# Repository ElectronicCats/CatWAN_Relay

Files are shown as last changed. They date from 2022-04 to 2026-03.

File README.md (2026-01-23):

# CatWAN Soldering Station - Control de Cautines con NFC

## Descripción

Sistema de control de cautines mediante autenticación NFC MIFARE S50 para ESP32-C6. Permite controlar el encendido y apagado de cautines solo con tarjetas NFC autorizadas, registrando todos los eventos en Google Sheets o n8n. Soporta múltiples dispositivos con identificadores únicos.

Incluye **feedback visual avanzado mediante pantalla OLED**, mostrando estados del sistema, conexión WiFi, eventos NFC y errores.

## Características

Este proyecto está diseñado como un sistema industrial ligero, robusto y escalable para el control de cautines mediante autenticación NFC. A continuación se describen las características de forma más detallada:

* ✅ **Autenticación NFC MIFARE S50**
  El sistema valida tarjetas NFC autorizadas usando su UID. Las tarjetas no autorizadas son rechazadas y el evento queda registrado.

* ✅ **Control de múltiples cautines (hasta 3 relés por dispositivo)**
  Cada tarjeta puede estar asociada a un relé específico o usar un relé por defecto. Esto permite que un solo dispositivo controle varias estaciones.

* ✅ **Gestión persistente de tarjetas autorizadas (SPIFFS)**
  Las tarjetas y asignaciones se almacenan en memoria flash, por lo que no se pierden al reiniciar el equipo.

* ✅ **Asignación manual de tarjetas a relés**
  Mediante comandos seriales es posible asignar una tarjeta a un cautín específico.

* ✅ **Identificador único de dispositivo (Device ID)**
  Cada ESP32 tiene un identificador único configurable que permite distinguir eventos cuando se usan múltiples estaciones.

* ✅ **Registro de eventos en Google Sheets o n8n**
  Todos los eventos (éxito, fallo, encendido, apagado, timeout) se envían vía HTTP en formato JSON.

* ✅ **WiFiManager con Captive Portal**
  Permite configurar WiFi y la URL de n8n sin recompilar el firmware.

* ✅ **Feedback visual mediante OLED y LED**
  La pantalla OLED muestra el estado del sistema (bienvenida, esperando tarjeta, tarjeta válida, errores, timeout).

* ✅ **Sistema de seguridad con timeout automático**
  Si un cautín permanece encendido más del tiempo configurado, se apaga automáticamente.

* ✅ **Comandos seriales para gestión y debug**
  Permite mantenimiento y diagnóstico sin necesidad de reprogramar el equipo.

* ✅ Autenticación NFC MIFARE S50

* ✅ Control de múltiples cautines (hasta 3 relés por dispositivo)

* ✅ Gestión de tarjetas autorizadas (almacenamiento local SPIFFS)

* ✅ Asignación manual de tarjetas a relés específicos

* ✅ Identificador único de dispositivo (Device ID)

* ✅ Registro de eventos en Google Sheets o n8n

* ✅ WiFi Manager con captive portal para configuración

* ✅ Feedback visual por **pantalla OLED (I2C)**

* ✅ Feedback visual por LED verde

* ✅ Sistema de seguridad con timeout automático (2 horas)

* ✅ Comandos seriales para gestión y debug

## Hardware Requerido

* **ESP32-C6** - Microcontrolador con WiFi
* **PN532** - Módulo NFC (I2C)
* **Pantalla OLED** - SSD1306 / SH1106 (I2C)
* **Relé/es** - Para controlar cautín/es (hasta 3 por dispositivo)
* **LED Verde** - Feedback de éxito
* **Fuente de alimentación** - 5V o 3.3V según requerimientos

## Conexiones Hardware

### PN532 (I2C)

* VCC → 3.3V
* GND → GND
* SDA → I2C Data (pines por defecto del ESP32-C6)
* SCL → I2C Clock (pines por defecto del ESP32-C6)

### Pantalla OLED (I2C)

* VCC → 3.3V
* GND → GND
* SDA → I2C Data
* SCL → I2C Clock

**Nota:** El PN532 y la OLED comparten el bus I2C.

### Relés

* RELAY_1 → GPIO 8 (Cautín 1)
* RELAY_2 → GPIO 10 (Cautín 2)
* RELAY_3 → GPIO 1 (Cautín 3)

### Feedback

* LED_GREEN → GPIO 11

**Nota:** Los pines son configurables en `config.h`

## Instalación

### 1. Librerías Requeridas

Instala las siguientes librerías desde el Arduino Library Manager:

* **Adafruit PN532** – Comunicación NFC
* **WiFiManager** – Gestión de WiFi
* **ArduinoJson** – Parsing de JSON
* **Adafruit SSD1306** – Control de pantalla OLED
* **Adafruit GFX Library** – Gráficos para OLED
* **SPIFFS** – Sistema de archivos (incluido en ESP32)

### 2. Archivos Nuevos Añadidos

El proyecto incluye un gestor dedicado para la pantalla OLED:

```
/oledManager.h
/oledManager.cpp
```

**Funciones principales de `oledManager`:**

* Inicialización de la pantalla
* Mensajes de estado (boot, WiFi, NFC)
* Visualización de UID
* Mensajes de éxito / error
* Indicadores de envío HTTP

### 3. Configuración

1. Abre `config.h` y configura:

   * `DEVICE_ID`
   * Pines de relés y LED
   * URL de Google Sheets o n8n
   * Parámetros de seguridad

2. Configura el tipo de backend:

```cpp
#define USE_GOOGLE_APPS_SCRIPT false
#define USE_N8N true
```

3. Configura la URL del webhook de n8n:

```cpp
#define N8N_WEBHOOK_URL "https://tu-n8n/webhook/catwan"
```

## Documentación de Funciones Principales

### setup()

Función de inicialización del sistema. Se ejecuta una sola vez al encender el dispositivo.

Responsabilidades:

* Inicializar comunicación serial
* Montar SPIFFS
* Configurar WiFi mediante WiFiManager
* Inicializar PN532
* Inicializar pantalla OLED
* Mostrar mensaje de bienvenida

---

### loop()

Función principal de ejecución continua.

Responsabilidades:

* Verificar conexión WiFi
* Revisar si el sistema está listo
* Mostrar estado "Esperando tarjeta" en OLED
* Detectar tarjetas NFC
* Procesar lógica de autorización
* Controlar relés
* Enviar eventos HTTP
* Manejar timeouts

---

### NFCManager::begin()

Inicializa el módulo PN532 y verifica que esté correctamente conectado por I2C.

### NFCManager::isCardPresent()

Devuelve `true` si una tarjeta NFC está presente en el lector.

### NFCManager::readCardUID()

Lee el UID de la tarjeta detectada y lo devuelve como `String`.

### NFCManager::reset()

Reinicia el estado del lector para evitar múltiples lecturas de la misma tarjeta.

---

### OLEDManager::showWelcome()

Muestra un mensaje de bienvenida al encender el dispositivo.

### OLEDManager::showWaiting()

Muestra el mensaje "Esperando tarjeta NFC" cuando el sistema está en reposo.

### OLEDManager::showCardAdded(uid)

Muestra el UID de la tarjeta detectada y confirma la acción realizada.

### OLEDManager::showTimeout()

Muestra un mensaje de error cuando se excede el tiempo de espera para detectar tarjeta.

---

### sendEventToN8n(json)

Envía un payload JSON vía HTTP POST a n8n o Google Sheets.
Incluye información del dispositivo, tarjeta, acción y duración.

---

## Uso

### Primera Configuración WiFi

1. El dispositivo crea un AP:

   * **SSID:** `CatWAN-SolderingStation`
   * **Password:** `soldering123`
2. Configura tu red WiFi desde el portal cautivo
3. El estado se muestra en la pantalla OLED

### Operación Normal

1. Presenta tarjeta NFC
2. OLED muestra UID y acción
3. Relé cambia de estado
4. Evento enviado a Google Sheets o n8n
5. OLED confirma envío exitoso

## Arquitectura del Software

El firmware está organizado de forma modular para facilitar mantenimiento, escalabilidad y depuración. Cada módulo tiene una responsabilidad clara.

### Módulos Principales

* **CATWAN_RELAY.ino**
  Archivo principal. Contiene `setup()` y `loop()`, coordina todos los managers y define el flujo general del sistema.

* **NFCManager**
  Encapsula toda la lógica relacionada con el PN532:

  * Inicialización del lector NFC
  * Detección de tarjetas
  * Lectura del UID
  * Reset del lector para evitar lecturas duplicadas

* **CardManager**
  Gestiona las tarjetas autorizadas:

  * Agregar / eliminar tarjetas
  * Asignar tarjetas a relés
  * Guardar y leer datos desde SPIFFS

* **RelayManager**
  Controla los relés físicos:

  * Encender / apagar relés
  * Llevar control del estado actual
  * Medir tiempo de encendido

* **WiFiManagerHelper**
  Extiende WiFiManager para:

  * Configurar WiFi
  * Configurar la URL de n8n desde el captive portal

* **OLEDManager (nuevo)**
  Maneja la pantalla OLED por I2C:

  * Mensaje de bienvenida
  * Estado "Esperando tarjeta"
  * Mostrar UID leído
  * Mostrar mensajes de error y timeout

* **FeedbackManager**
  Controla el LED verde para indicar éxito visual inmediato.

---

## Flujo General del Sistema

```text
[ Encendido ]
      |
      v
[ Inicialización ]
- Serial
- WiFi
- SPIFFS
- PN532
- OLED
      |
      v
[ Mostrar Bienvenida OLED ]
      |
      v
[ Esperando Tarjeta NFC ] <-------------------+
      |                                      |
      v                                      |
[ Tarjeta Detectada ]                         |
      |                                      |
      v                                      |
[ ¿Tarjeta Autorizada? ] -- NO --> [ Error ] -+
      |
     SI
      |
      v
[ Activar / Desactivar Relé ]
      |
      v
[ Enviar JSON a n8n / Sheets ]
      |
      v
[ Mostrar Resultado en OLED ]
      |
      v
[ Volver a Espera ]
```

---

## Estructura de Datos

### JSON enviado por ESP32

### JSON enviado a n8n

```json
{
  "ts": "02:30:45",
  "dev": "ESTACION1",
  "uid": "04A5B6C7D8",
  "act": "ENCENDER",
  "st": "EXITO",
  "rel": 0,
  "dur": 120000
}
```

### Uso del JSON en n8n

En n8n el JSON puede usarse para:

* Buscar usuario por UID
* Buscar estación por Device ID
* Registrar eventos
* Calcular tiempo de uso
* Activar alertas o dashboards

## Flujo del Sistema

1. Lectura NFC
2. Validación local
3. Acción sobre relé
4. Feedback OLED + LED
5. Envío HTTP POST
6. Registro centralizado

## Seguridad

* Timeout automático configurable
* Debounce de lecturas NFC
* Registro de intentos fallidos
* Sin almacenamiento de nombres en el ESP32

## Troubleshooting

### HTTP Error: -1

* No hay conexión WiFi
* URL inválida
* Error DNS
* Webhook n8n inactivo

### OLED no muestra información

* Verifica dirección I2C (0x3C / 0x3D)
* Verifica librerías Adafruit
* Confirma alimentación estable

---
## Licencia

Este firmware está bajo licencia GNU AGPL v3.0.

---

## 👨‍💻 Autor

ElectronicCats.

---
## Soporte

Para más información, visita: https://electroniccats.com

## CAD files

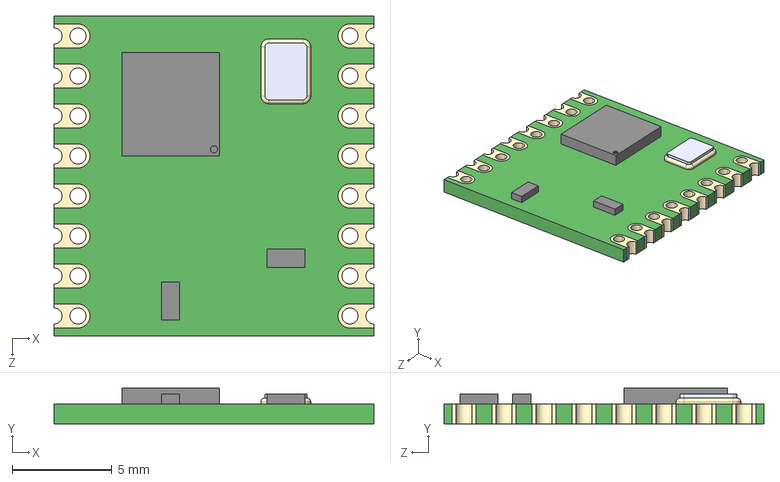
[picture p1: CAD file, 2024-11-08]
Hw/3D/RFM95W-915S2--3DModel-STEP-56544.STEP
16.0 x 1.80 x 16.0 mm

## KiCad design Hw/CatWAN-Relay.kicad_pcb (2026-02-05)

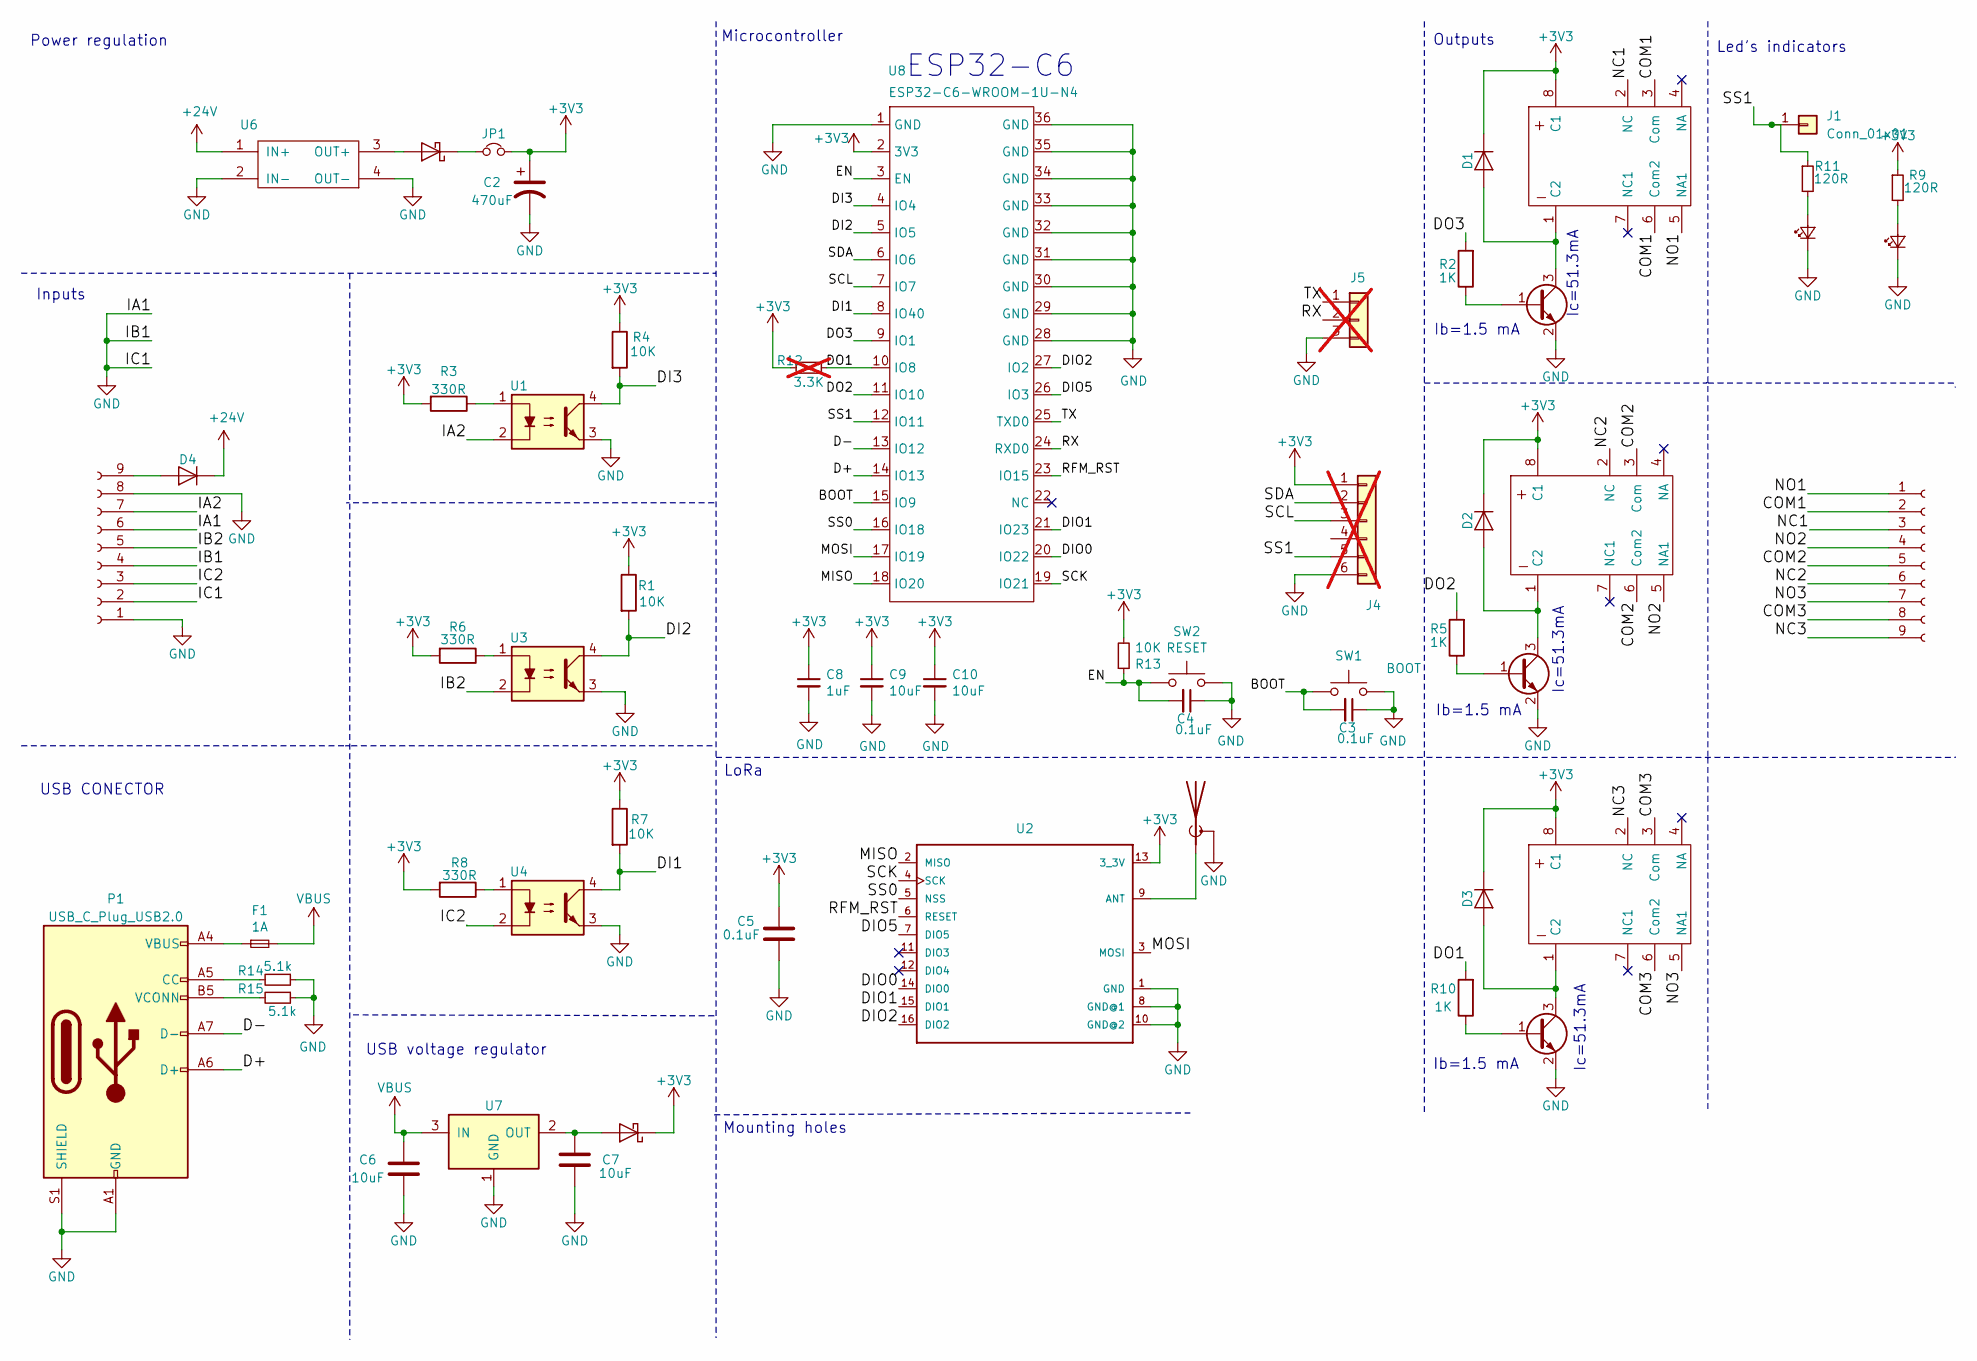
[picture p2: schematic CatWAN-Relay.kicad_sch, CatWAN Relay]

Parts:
AE1: Antenna_Shield; U.FL_Molex_MCRF_73412-0110_Vertical; LCSC# C7426714
C2: 470uF; C_Elec_6.3x7.7; LCSC# C5354997
C3, C4, C5: 0.1uF; C_0603_1608Metric; LCSC# C15725
C6, C7, C9, C10: 10uF; C_0603_1608Metric; LCSC# C85713
C8: 1uF; C_0603_1608Metric; LCSC# C15849
D1, D2, D3, D4: SOD4007-MS; D_SOD-123F; LCSC# C3008061
D5, D8: MBR120; D_SOD-123; LCSC# C130880
D6: ON; LED_0805_2012Metric_Pad1.15x1.40mm_HandSolder; LCSC# C130114
D7: SS0_LED; LED_0805_2012Metric_Pad1.15x1.40mm_HandSolder; LCSC# C130114
F1: 1A; Fuse_0603_1608Metric; LCSC# C151139
J1: Conn_01x01; PinHeader_1x01_P2.54mm_Vertical
J2: INPUTS; TerminalBlock_Phoenix_MKDS-1,5-9-5.08_1x09_P5.08mm_Horizont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
J3: OUTPUTS; TerminalBlock_Phoenix_MKDS-1,5-9-5.08_1x09_P5.08mm_Horizont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
J4: I2C; PinHeader_1x06_P2.54mm_Vertical; not fitted
J5: Serial; PinHeader_1x03_P2.54mm_Vertical; not fitted
JP1: ADJ; PinHeader_1x02_P2.54mm_Vertical
P1: USB_C_Plug_USB2.0; C393939; LCSC# C393939
Q1, Q2, Q3: MMBT2222A; SOT-23; LCSC# C916372
R1, R4, R7, R13: 10K; R_0603_1608Metric; LCSC# C15401
R2, R5, R10: 1K; R_0603_1608Metric; LCSC# C115325
R3, R6, R8: 330R; R_0603_1608Metric; LCSC# C25231
R9, R11: 120R; R_0603_1608Metric; LCSC# C22787
R12: 3.3K; R_0603_1608Metric; not fitted
R14, R15: 5.1k; R_0603_1608Metric; LCSC# C122969
SW1: BOOT; SW_Push_SPST_NO_Alps_SKRK; LCSC# C455281
SW2: RESET; SW_Push_SPST_NO_Alps_SKRK; LCSC# C455281
U1, U3, U4: AT3H7C-CuH-S; SOP-4_4.4x2.6mm_P1.27mm; LCSC# C20612661
U2: RFM95W-915-868; RFM95W
U6: LM2596_DC-DC; LM2596DC-DC
U7: AP2114H-3.3TRG1; SOT-223-3_TabPin2; LCSC# C150716
U8: ESP32-C6-WROOM-1U-N4; ESP32-C6-WROOM-1U
Y1, Y2, Y3: UD2-3NU; LCSC# C90259

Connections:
+3V3: C2.1, C5.1, C8.1, C9.1, C10.1, D1.1 (K), D2.1 (K), D3.1 (K), D5.1 (K), J4.1, JP1.2, R1.1, R3.2, R4.1, R6.2, R7.1, R8.2, R9.1, R12.2, R13.2, U2.13 (3_3V), U8.2 (3V3), Y1.8 (C1), Y2.8 (C1), Y3.8 (C1)
+24V: D4.1 (K), U6.1 (IN+)
/<NO NET>: J4.4
/BOOT: C3.2, SW1.2, U8.15 (IO9)
/COM1: J3.2, Y1.3 (Com), Y1.6 (Com2)
/COM2: J3.5, Y2.3 (Com), Y2.6 (Com2)
/COM3: J3.8, Y3.3 (Com), Y3.6 (Com2)
/D+: P1.A6 (D+), U8.14 (IO13)
/D-: P1.A7 (D-), U8.13 (IO12)
/DI1: R7.2, U4.4, U8.8 (IO40)
/DI2: R1.2, U3.4, U8.5 (IO5)
/DI3: R4.2, U1.4, U8.4 (IO4)
/DIO0: U2.14 (DIO0), U8.20 (IO22)
/DIO1: U2.15 (DIO1), U8.21 (IO23)
/DIO2: U2.16 (DIO2), U8.27 (IO2)
/DIO5: U2.7 (DIO5), U8.26 (IO3)
/DO1: R10.2, R12.1, U8.10 (IO8)
/DO2: R5.2, U8.11 (IO10)
/DO3: R2.2, U8.9 (IO1)
/EN: C4.2, R13.1, SW2.2, U8.3 (EN)
/IA2: J2.7, U1.2
/IB2: J2.5, U3.2
/IC2: J2.3, U4.2
/MISO: U2.2 (MISO), U8.18 (IO20)
/MOSI: U2.3 (MOSI), U8.17 (IO19)
/NC1: J3.3, Y1.2 (NC)
/NC2: J3.6, Y2.2 (NC)
/NC3: J3.9, Y3.2 (NC)
/NO1: J3.1, Y1.5 (NA1)
/NO2: J3.4, Y2.5 (NA1)
/NO3: J3.7, Y3.5 (NA1)
/RFM_RST: U2.6 (RESET), U8.23 (IO15)
/RX: J5.2, U8.24 (RXD0)
/SCK: U2.4 (SCK), U8.19 (IO21)
/SCL: J4.3, U8.7 (IO7)
/SDA: J4.2, U8.6 (IO6)
/SS0: U2.5 (NSS), U8.16 (IO18)
/SS1: J1.1, J4.5, R11.1, U8.12 (IO11)
/TX: J5.1, U8.25 (TXD0)
GND: AE1.2 (Shield), C2.2, C3.1, C4.1, C5.2, C6.2, C7.2, C8.2, C9.2, C10.2, D6.1 (K), D7.1 (K), J2.1, J2.2, J2.4, J2.6, J2.8, J4.6, J5.3, P1.A1 (GND), P1.A12 (GND), P1.B1 (GND), P1.B12 (GND), P1.S1 (SHIELD), Q1.2 (E), Q2.2 (E), Q3.2 (E), R14.1, R15.1, SW1.1, SW2.1, U1.3, U2.1 (GND), U2.8 (GND@1), U2.10 (GND@2), U3.3, U4.3, U6.2 (IN-), U6.4 (OUT-), U7.1 (GND), U8.1 (GND), U8.28 (GND), U8.29 (GND), U8.30 (GND), U8.31 (GND), U8.32 (GND), U8.33 (GND), U8.34 (GND), U8.35 (GND), U8.36 (GND), U8.37 (GND)
unnamed: AE1.1 (A), U2.9 (ANT)
unnamed: D1.2 (A), Q1.3 (C), Y1.1 (C2)
unnamed: D2.2 (A), Q2.3 (C), Y2.1 (C2)
unnamed: D3.2 (A), Q3.3 (C), Y3.1 (C2)
unnamed: D4.2 (A), J2.9
unnamed: C7.1, D5.2 (A), U7.2 (OUT)
unnamed: D6.2 (A), R9.2
unnamed: D7.2 (A), R11.2
unnamed: D8.2 (A), U6.3 (OUT+)
unnamed: D8.1 (K), JP1.1
unnamed: F1.1, P1.A4 (VBUS), P1.A9 (VBUS), P1.B4 (VBUS), P1.B9 (VBUS)
unnamed: P1.A5 (CC), R14.2
unnamed: P1.B5 (VCONN), R15.2
unnamed: Q1.1 (B), R2.1
unnamed: Q2.1 (B), R5.1
unnamed: Q3.1 (B), R10.1
unnamed: R3.1, U1.1
unnamed: R6.1, U3.1
unnamed: R8.1, U4.1
VBUS: C6.1, F1.2, U7.3 (IN)

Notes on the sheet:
LoRa
Inputs
Microcontroller
Ic=51.3mA
USB voltage regulator
USB CONECTOR
Power regulation
Mounting holes
ESP32-C6
Ib=1.5 mA
Led's indicators
Outputs

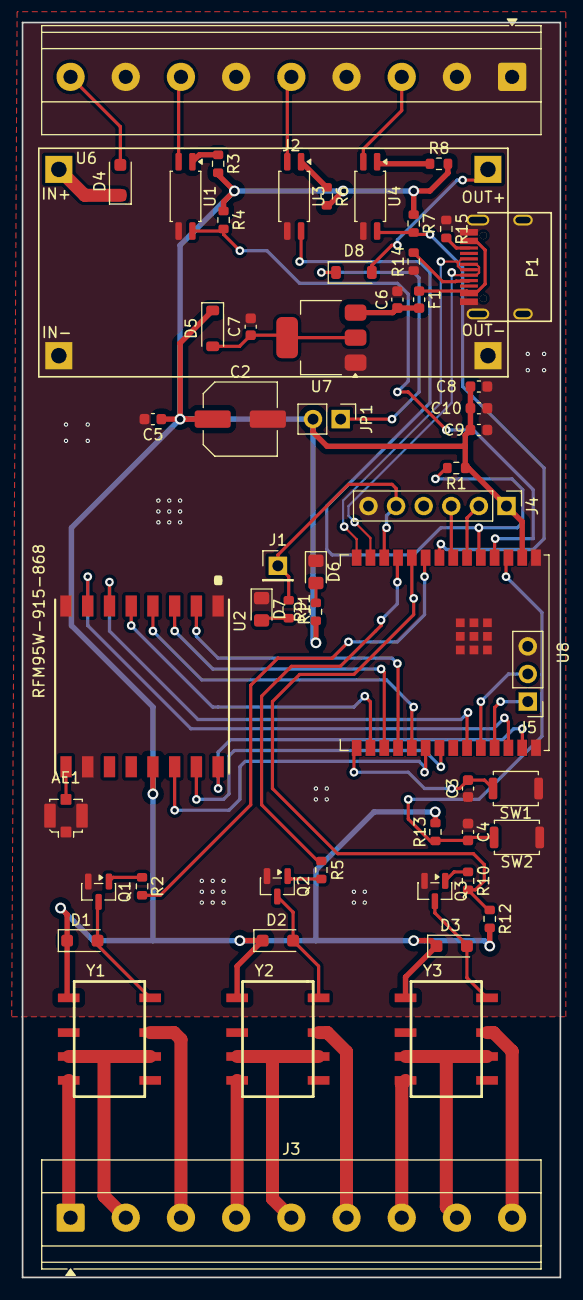
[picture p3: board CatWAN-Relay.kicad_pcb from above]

Board: 2 copper layers, 49.5 x 115.5 mm, 56 parts (0 on the bottom side), 59 nets.

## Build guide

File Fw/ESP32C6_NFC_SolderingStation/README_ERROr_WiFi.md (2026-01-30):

# 📘 README – Corrección de errores NFC y sobresaturación por WiFiManager

## 1. Contexto del problema

Durante el desarrollo del proyecto **CATWAN_RELAY**, se integraron varios módulos críticos en un ESP32, principalmente:

* **PN532 (NFC) vía I2C**
* **WiFiManager** para configuración dinámica de red
* Comunicación con servicios externos (n8n)

Conforme el proyecto creció, comenzaron a presentarse errores constantes relacionados con NFC, identificados principalmente como **"NFC ERROR"**, pérdida total de detección de tarjetas y ausencia de mensajes por el monitor Serial.

---

## 2. Síntomas observados

1. El monitor Serial dejaba de mostrar información después de cargar nuevo código.
2. El PN532 no detectaba tarjetas NFC aunque el cableado fuera correcto.
3. Aparecían errores de compilación y linker relacionados con `NFCManager`.
4. WiFiManager se quedaba bloqueado o reiniciaba el sistema.
5. El sistema funcionaba parcialmente si se deshabilitaba WiFiManager o NFC, pero no ambos juntos.

---

## 3. Causas reales del problema

### 3.1 Sobresaturación del sistema por WiFiManager

WiFiManager crea:

* Portales cautivos
* Servidor web
* DNS interno

Esto **consume memoria, tiempo de CPU y bloquea el loop principal**, especialmente si:

* Se inicializa antes que otros periféricos
* No se limita su tiempo de ejecución

Esto provocaba que:

* El bus I2C no se inicializara correctamente
* El PN532 no respondiera a `getFirmwareVersion()`

---

### 3.2 Uso incorrecto del constructor de Adafruit_PN532

Se intentaron múltiples constructores inválidos:

* `Adafruit_PN532(Wire)` ❌
* `Adafruit_PN532(PN532_I2C_ADDRESS)` ❌

La librería **NO soporta esos constructores**.

El constructor correcto para I2C es:

```
Adafruit_PN532(uint8_t irq, uint8_t reset, TwoWire *theWire)
```

Al no usarlo correctamente:

* El objeto `nfc` se creaba mal
* Las llamadas internas fallaban silenciosamente

---

### 3.3 Inicialización incorrecta del bus I2C

El PN532 se conectó usando:

* **SDA = GPIO 6**
* **SCL = GPIO 7**

Problemas:

* GPIO 6 está reservado internamente (SPI Flash)
* GPIO 7 no es un pin I2C recomendado

Esto hacía que:

* `Wire.begin()` no funcionara correctamente
* El PN532 nunca respondiera

---

### 3.4 Inconsistencias entre `.h` y `.cpp`

Se detectaron errores graves de diseño:

* Métodos declarados en `.h` pero no definidos en `.cpp`
* Firmas distintas (`readCardUID()` vs `readCardUID(char*)`)
* Destructor declarado pero no implementado

Esto causaba:

* Errores de linker (`undefined reference`)
* Fallos en tiempo de ejecución

---

## 4. Solución aplicada

### 4.1 Reestructuración de NFCManager

Se unificaron completamente las firmas:

* `bool readCardUID(char* uidBuffer)`
* Eliminación de métodos no usados
* Estado interno claro (`initialized`)

---

### 4.2 Corrección del constructor PN532

Se adoptó el constructor correcto:

```
Adafruit_PN532 nfc(IRQ_PIN, RESET_PIN, &Wire);
```

Y se inicializó correctamente:

```
Wire.begin(SDA_PIN, SCL_PIN);
```

---

### 4.3 Corrección de pines I2C

Se cambiaron los pines a valores seguros:

* SDA = GPIO 21
* SCL = GPIO 22

Esto permitió:

* Comunicación estable
* Lectura correcta del firmware PN532

---

### 4.4 Control de ejecución de WiFiManager

Se evitó que WiFiManager:

* Bloqueara el `loop()`
* Se ejecutara permanentemente

Ahora:

* Se inicializa solo cuando es necesario
* No interfiere con NFC

---

## 5. Resultado final

✔ NFC detecta tarjetas de forma estable
✔ UID leído correctamente sin repeticiones
✔ WiFiManager funciona sin bloquear el sistema
✔ No hay errores de compilación ni linker
✔ Monitor Serial estable

---

## 6. Conclusión técnica

El problema **NO era el PN532**, sino:

* Mala inicialización de I2C
* Uso incorrecto de librerías
* Saturación del sistema por WiFiManager
* Errores estructurales en C++

Una correcta arquitectura y control de recursos permitió estabilizar todo el sistema.

---

📌 *Este README documenta los cambios realizados para futuras referencias, mantenimiento y evaluación técnica del proyecto.*

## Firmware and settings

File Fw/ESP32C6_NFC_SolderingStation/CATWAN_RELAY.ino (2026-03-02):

/*
 * CatWAN Soldering Station - Control de Cautines con NFC
 * ESP32-C6 con PN532 para autenticación MIFARE S50
 *
 * Funcionalidades:
 * - Control de cautines mediante autenticación NFC
 * - Registro de eventos en Google Sheets o n8n
 * - Gestión de tarjetas autorizadas (SPIFFS)
 * - Feedback visual y sonoro
 * - WiFi Manager para configuración de red
 */
#include "card_manager.h"
#include "config.h"
#include "feedback_manager.h"
#include "nfc_manager.h"
#include "oled_manager.h"
#include "relay_manager.h"
#include "sheets_manager.h"
#include <SPIFFS.h>
#include <WiFi.h>
#include <WiFiManager.h>
#include <Wire.h>

char n8n_url[150] = "";
char n8n_time_url[150] = "";

// Instancias globales
RelayManager relayManager;
CardManager cardManager;
SheetsManager sheetsManager;
FeedbackManager feedbackManager;
WiFiManager wifiManager;
OLEDManager oledManager;
EventData queuedEvent;
NFCManager nfcManager;
// 255 = pin dummy (no usado físicamente)

// Variables de estado
String pendingCardName = "";
bool waitingForCardName = false;
bool systemReady = false;
int currentRelayIndex = 0;       // Relé activo actualmente (0 = primer cautín)
bool waitingForCard = false;     // Flag para modo de espera de tarjeta
unsigned long waitStartTime = 0; // Tiempo de inicio de espera
unsigned long lastWifiCheck = 0;
bool pendingEvent = false;
unsigned long n8nEpoch = 0;
unsigned long n8nMillis = 0;
bool timeSynced = false;
bool triedTimeSync = false;
bool nfcBusy = false;
String lastScannedUID = "";      // Stores the last card ID read
unsigned long lastCardTime = 0;  // Stores the timestamp of the last read
unsigned long oledClearTime = 0; // Tiempo para limpiar la pantalla OLED

// Prototipos de funciones
void setupWiFi();
void processNFC();
void handleSerialCommands();
void toggleSolderingIron(int relayIndex, String cardUID);
void printHelp();
void printStatus();
void reconnectWiFi();
void handleWiFi();
void handleAddCard(const String &uidStr);
void handleAccessCard(const String &uidStr);

String getStationIdByRelay(int relayIndex) {
  if (relayIndex >= 0 && relayIndex < NUM_STATIONS) {
    return String(stations[relayIndex].stationId);
  }
  return "DESCONOCIDA";
}

void processCard(String uid) {
  Serial.print("Tarjeta detectada: ");
  Serial.println(uid);

  if (cardManager.isCardAuthorized(uid)) {
    int relay = cardManager.getCardRelay(uid);
    toggleSolderingIron(relay, uid);
  } else {
    feedbackManager.showError();
    oledManager.showMessage("Acceso denegado");
  }
}

void saveN8NURL() {
  File f = SPIFFS.open("/n8n.txt", "w");
  if (f) {
    f.println(n8n_url);
    f.println(n8n_time_url);
    f.close();
  }
}

void setup() {
  Serial.begin(115200);
  delay(1000);

  Wire.begin();
  delay(100);

  oledManager.begin();
  oledManager.showWelcome();

  feedbackManager.begin();
  delay(2000);
  feedbackManager.showWaiting();

  if (!SPIFFS.begin(true)) {

    Serial.println("SPIFFS ERROR");
  }

  loadN8NURL(); // <-- cargar URL guardada
  setupWiFi();  // <-- aquí se mostrará el campo para n8n
  saveN8NURL(); // <-- guardar la nueva si el usuario la cambió

  sheetsManager.setN8NURL(String(n8n_url)); // <-- usar URL configurada
  sheetsManager.setN8NTimeURL(String(n8n_time_url));

  // Sincronizar hora si estamos conectados
  if (WiFi.status() == WL_CONNECTED) {
    sheetsManager.syncTime();
  }

  WiFi.setSleep(false);

  if (!nfcManager.begin()) {
#if DEBUG_SERIAL
    Serial.println("NFC ERROR");
#endif
    feedbackManager.showError();
    delay(2000);
  }

  relayManager.begin();

  if (!cardManager.begin()) {
#if DEBUG_SERIAL
    Serial.println("Card Manager ERROR");
#endif
  }

  sheetsManager.begin();

#if USE_GOOGLE_APPS_SCRIPT
  if (String(GOOGLE_SCRIPT_URL).length() == 0) {
#if DEBUG_SERIAL
    Serial.println("WARN: No URL config");
#endif
  }
#endif

#if USE_N8N
  if (String(N8N_WEBHOOK_URL).length() == 0) {
#if DEBUG_SERIAL
    Serial.println("WARN: No URL config");
#endif
  }
#endif

  systemReady = true;
#if DEBUG_SERIAL
  Serial.println("Ready");
#endif

  feedbackManager.showSuccess();
  delay(500);
  feedbackManager.showWaiting();
}

void loadN8NURL() {
  if (SPIFFS.exists("/n8n.txt")) {
    File f = SPIFFS.open("/n8n.txt", "r");
    if (f) {
      String line = f.readStringUntil('\n');
      line.trim();
      line.toCharArray(n8n_url, sizeof(n8n_url));

      if (f.available()) {
        String line2 = f.readStringUntil('\n');
        line2.trim();
        line2.toCharArray(n8n_time_url, sizeof(n8n_time_url));
      }

      f.close();
    }
  }
}

void loop() {
  handleWiFi();

  // Sync queued events to Sheets/n8n when online
  // Sync queued events to Sheets/n8n when online
  if (pendingEvent && WiFi.status() == WL_CONNECTED) {
    sheetsManager.logEvent(queuedEvent);
    pendingEvent = false; // Intentar solo una vez y liberar
  }

  if (oledClearTime > 0 && millis() > oledClearTime) {
    oledManager.clear();
    oledClearTime = 0;
  }

  relayManager.checkSafetyTimeout();

  if (Serial.available()) {
    handleSerialCommands();
  }

  // Core NFC Logic
  // Procesar NFC
  if (systemReady && nfcManager.isInitialized()) {
    if (!waitingForCard) {
      processNFC();
    } else {
      // Modo de espera para agregar tarjeta
      if (waitStartTime == 0) {
        waitStartTime = millis();
      }

      // Verificar timeout (30 segundos)
      if (millis() - waitStartTime > 30000) {
        Serial.println("Timeout: No se detecto tarjeta");
        waitingForCard = false;
        waitStartTime = 0;
      } else {
        // Intentar leer tarjeta
        if (nfcManager.isCardPresent()) {
          String uid = nfcManager.readCardUID();
          if (uid.length() > 0) {
            // Tarjeta detectada, agregarla
            if (cardManager.addCard(uid, pendingCardName)) {
              Serial.println("Tarjeta agregada exitosamente");
            } else {
              Serial.println("Error al agregar tarjeta");
            }
            waitingForCard = false;
            waitStartTime = 0;
            nfcManager.reset(); // Resetear para evitar lectura repetida
          }
        }
      }
    }
  }

  delay(10); // Stability delay
}
void processNFC() {
  // Detectar tarjeta
  if (nfcManager.isCardPresent()) {
    String uid = nfcManager.readCardUID();

    if (uid.length() > 0) {
      // Nueva tarjeta detectada
      lastScannedUID = uid;
      lastCardTime = millis();

#if DEBUG_SERIAL
      Serial.print("Card: ");
      Serial.println(uid);
#endif

      if (cardManager.isCardAuthorized(uid)) {
#if DEBUG_SERIAL
        Serial.println("OK");
#endif
        feedbackManager.showSuccess();

        // Obtener el relé asignado a esta tarjeta
        int assignedRelay = cardManager.getCardRelay(uid);

        // Si la tarjeta no tiene asignación, usar el relé por defecto (0)
        if (assignedRelay < 0) {
          assignedRelay = currentRelayIndex; // Usar relé por defecto
#if DEBUG_SERIAL
          Serial.println("Tarjeta sin asignación, usando relé por defecto");
#endif
        }

        // Toggle del cautín asignado (encender/apagar)
        toggleSolderingIron(assignedRelay, uid);

      } else {
#if DEBUG_SERIAL
        Serial.println("DENIED");
#endif
        feedbackManager.showError();

        // Registrar intento fallido
        EventData event;
        event.timestamp = "";
        event.deviceId = String(DEVICE_ID);
        event.cardUID = uid;
        event.action = "ACCESO DENEGADO";
        event.status = "FALLO";
        event.relayIndex = -1;
        event.duration = 0;

        sheetsManager.logEvent(event);
      }

      delay(1000); // Delay para evitar lectura múltiple
      feedbackManager.showWaiting();
    }
  } else {
    // No hay tarjeta presente - resetear después de un tiempo
    if (lastScannedUID.length() > 0 && (millis() - lastCardTime) > 3000) {
      nfcManager.reset();
      lastScannedUID = "";
    }
  }
}

void handleWiFi() {

  static unsigned long lastAttempt = 0;

  static wl_status_t lastStatus = WL_IDLE_STATUS;

  wl_status_t status = WiFi.status();

  if (status != lastStatus) {
    lastStatus = status;

    if (status == WL_CONNECTED) {
      Serial.println("WiFi conectado");
      Serial.print("IP: ");
      Serial.println(WiFi.localIP());
      oledManager.showMessage("WiFi OK");
    } else {
      Serial.println("WiFi desconectado");
      oledManager.showMessage("WiFi OFF");
    }
  }

  if (status != WL_CONNECTED && millis() - lastAttempt > 10000) {
    lastAttempt = millis();
    WiFi.reconnect();
  } // Si se perdió conexión, ESP32 se reconecta solo
}

void setupWiFi() {

  WiFiManagerParameter custom_n8n_url("n8nurl", "URL Webhook n8n (Logs)",
                                      n8n_url, 150);

  WiFiManagerParameter custom_n8n_time_url(
      "n8ntimeurl", "URL Webhook n8n (Hora)", n8n_time_url, 150);

  wifiManager.addParameter(&custom_n8n_url);
  wifiManager.addParameter(&custom_n8n_time_url);

  wifiManager.setConfigPortalTimeout(180);

  if (!wifiManager.autoConnect(WIFI_AP_NAME, WIFI_AP_PASS)) {
    Serial.println("WiFi FAIL - Restart");
    delay(3000);
    ESP.restart();
  }

  // Guardar lo que el usuario escribió
  strncpy(n8n_url, custom_n8n_url.getValue(), sizeof(n8n_url));
  strncpy(n8n_time_url, custom_n8n_time_url.getValue(), sizeof(n8n_time_url));

  Serial.print("n8n URL logs: ");
  Serial.println(n8n_url);
  Serial.print("n8n URL hora: ");
  Serial.println(n8n_time_url);

  WiFi.setAutoReconnect(true);
  WiFi.persistent(false);
  WiFi.setSleep(false);
}

void toggleSolderingIron(int relayIndex, String cardUID) {
  if (waitingForCard)
    return;

  bool currentState = relayManager.getRelayState(relayIndex);
  bool newState = !currentState;

  String action = newState ? "ENCENDER" : "APAGAR";
  unsigned long duration =
      newState ? 0 : relayManager.getRelayUptime(relayIndex);
  String stationId = getStationIdByRelay(relayIndex);
  String cardName = cardManager.getCardName(cardUID);

  if (cardName.length() == 0) {
    cardName = "SIN_NOMBRE";
  }

  if (newState) {
    oledManager.showWelcomeName(cardName);
  } else {
    oledManager.showGoodbyeName(cardName);
  }

  oledClearTime = millis() + 3000; // Limpiar pantalla en 3 segundos

  relayManager.setRelay(relayIndex, newState);

  EventData event;
  event.timestamp = "";
  event.deviceId = String(DEVICE_ID);
  event.stationId = stationId; // ← estación real
  event.cardUID = cardUID;
  event.action = action;
  event.status = "EXITO";
  event.relayIndex = relayIndex;
  event.duration = duration;
  event.cardName = cardName;

  String jsonPayload = "{\"uid\":\"" + cardUID + "\", \"act\":\"" + action +
                       "\", \"relay\":" + String(relayIndex) + "}";

  queuedEvent = event;
  pendingEvent = true;

#if DEBUG_SERIAL
  Serial.print("Estación ");
  Serial.print(stationId);
  Serial.print(": ");
  Serial.println(newState ? "ON" : "OFF");
#endif

  feedbackManager.showWaiting();
  delay(300);

  nfcBusy = false;
}

void handleSerialCommands() {
  String command = Serial.readStringUntil('\n');
  command.trim();
  command.replace("\r", ""); // Remove any carriage return character
  command.toUpperCase();

  if (command.length() == 0)
    return;

  oledManager.showCommand(command);

#if DEBUG_SERIAL
  Serial.print("Cmd: ");
  Serial.println(command);
#endif

  // ====== MODO CAPTURA DE NOMBRE ======
  if (waitingForCardName) {
    pendingCardName = command;
    pendingCardName.trim();

    if (pendingCardName.length() > 0) {
      Serial.print("Nombre recibido: ");
      Serial.println(pendingCardName);

      oledManager.showMessage("Acerque tarjeta NFC");

      waitingForCardName = false;
      waitingForCard = true;
      waitStartTime = 0;
    }
    return; // ← Return here, so we don't process it as a normal command
  }

  // ====== COMANDOS NORMALES ======
  if (command == CMD_HELP) {
    printHelp();

  } else if (command == CMD_STATUS) {
    printStatus();

  } else if (command == CMD_LIST_CARDS) {
    cardManager.listCards();

  } else if (command == CMD_LIST_ASSIGN) {
    cardManager.listAssignments();

  } else if (command.startsWith(CMD_ASSIGN_CARD)) {
    // Formato: ASSIGN_CARD <UID> <relay_index>
    // Ejemplo: ASSIGN_CARD 04A5B6C7D8 0
    int space1 = command.indexOf(' ');
    if (space1 > 0) {
      int space2 = command.indexOf(' ', space1 + 1);
      if (space2 > 0) {
        String uid = command.substring(space1 + 1, space2);
        uid.trim();
        uid.toUpperCase();
        int relayIndex = command.substring(space2 + 1).toInt();

        if (cardManager.assignCardToRelay(uid, relayIndex)) {
          Serial.println("Asignación exitosa");
        }
      } else {
        Serial.println("Formato: ASSIGN_CARD <UID> <relay_index>");
        Serial.println("Ejemplo: ASSIGN_CARD 04A5B6C7D8 0");
      }
    } else {
      Serial.println("Formato: ASSIGN_CARD <UID> <relay_index>");
      Serial.println("Índices de relé: 0, 1, 2 (Cautín 1, 2, 3)");
    }

  } else if (command == CMD_ADD_CARD) {
    Serial.println("Ingrese el nombre de la persona:");
    oledManager.showMessage("Ingrese nombre");

    pendingCardName = "";
    waitingForCardName = true;

    // Formato: ADD_CARD <UID> o ADD_CARD (sin UID para leer automáticamente)
    int spaceIndex = command.indexOf(' ');
    if (spaceIndex > 0) {
      // Método 1: UID proporcionado manualmente
      String uid = command.substring(spaceIndex + 1);
      uid.trim();
      if (cardManager.addCard(uid, "SIN_NOMBRE")) {
        Serial.println("Tarjeta agregada exitosamente");
      }
    } else {
      // Método 2: Esperar tarjeta NFC automáticamente
      Serial.println("Coloca una tarjeta NFC en el lector...");
      Serial.println("Tienes 60 segundos para colocar la tarjeta");
      waitingForCard = true;
      waitStartTime = 0; // Resetear tiempo
    }

  } else if (command.startsWith(CMD_REMOVE_CARD)) {
    // Formato: REMOVE_CARD <UID>
    int spaceIndex = command.indexOf(' ');
    if (spaceIndex > 0) {
      String uid = command.substring(spaceIndex + 1);
      uid.trim();
      if (cardManager.removeCard(uid)) {
        Serial.println("Tarjeta removida exitosamente");
      }
    } else {
      Serial.println("Formato: REMOVE_CARD <UID>");
    }

  } else if (command == CMD_CLEAR_CARDS) {
    Serial.println(
        "¿Eliminar todas las tarjetas? Escribe 'YES' para confirmar");
    delay(2000);
    if (Serial.available()) {
      String confirm = Serial.readStringUntil('\n');
      confirm.trim();
      confirm.toUpperCase();
      if (confirm == "YES") {
        cardManager.clearAllCards();
      } else {
        Serial.println("Operación cancelada");
      }
    }

  } else if (command.startsWith(CMD_TEST_RELAY)) {
    // Formato: TEST_RELAY <index> <state>
    // Ejemplo: TEST_RELAY 0 ON
    int space1 = command.indexOf(' ');
    if (space1 > 0) {
      int space2 = command.indexOf(' ', space1 + 1);
      if (space2 > 0) {
        int relayIndex = command.substring(space1 + 1, space2).toInt();
        String state = command.substring(space2 + 1);
        state.toUpperCase();

        bool relayState = (state == "ON" || state == "1");
        relayManager.setRelay(relayIndex, relayState);
        Serial.print("Relé ");
        Serial.print(relayIndex);
        Serial.print(" configurado a: ");
        Serial.println(relayState ? "ON" : "OFF");
      } else {
        Serial.println("Formato: TEST_RELAY <index> <ON|OFF>");
      }
    } else {
      Serial.println("Formato: TEST_RELAY <index> <ON|OFF>");
    }

  } else if (command == CMD_WIFI_RECONNECT) {
    reconnectWiFi();

  } else {
    Serial.println(
        "Comando no reconocido. Escribe 'HELP' para ver comandos disponibles");
  }
}

void printHelp() {
  Serial.println("\n=== Comandos Disponibles ===");
  Serial.println("HELP              - Mostrar esta ayuda");
  Serial.println("STATUS            - Estado del sistema");
  Serial.println("LIST_CARDS        - Listar tarjetas autorizadas");
  Serial.println("ADD_CARD          - Agregar tarjeta (coloca tarjeta NFC)");
  Serial.println("ADD_CARD <UID>    - Agregar tarjeta con UID manual");
  Serial.println("ASSIGN_CARD <UID> <relay> - Asignar tarjeta a cautín");
  Serial.println("  Ejemplo: ASSIGN_CARD 04A5B6C7D8 0");
  Serial.println("  Relés: 0=Cautín1, 1=Cautín2, 2=Cautín3");
  Serial.println("LIST_ASSIGN       - Listar asignaciones tarjeta-cautín");
  Serial.println("REMOVE_CARD <UID> - Remover tarjeta autorizada");
  Serial.println("CLEAR_CARDS       - Eliminar todas las tarjetas");
  Serial.println("TEST_RELAY <i> <ON|OFF> - Probar relé");
  Serial.println("WIFI_ RECONNECT   -Forzar reconexión WiFi");
  Serial.println("===========================\n");
}

void reconnectWiFi() {
  Serial.println("Reiniciando WiFi...");
  oledManager.showMessage("Reset WiFi");

  WiFi.disconnect(true);
  delay(200);
  WiFi.begin(); // usa credenciales guardadas
}

void printStatus() {
  Serial.println("\n=== Estado del Sistema ===");
  Serial.print("Device ID: ");
  Serial.println(DEVICE_ID);

  Serial.print("WiFi: ");
  Serial.println(WiFi.status() == WL_CONNECTED ? "Conectado" : "Desconectado");

  if (WiFi.status() == WL_CONNECTED) {
    Serial.print("IP: ");
    Serial.println(WiFi.localIP());
  }

  Serial.print("NFC: ");
  Serial.println(nfcManager.isInitialized() ? "OK" : "ERROR");

  Serial.print("Tarjetas autorizadas: ");
  Serial.println(cardManager.getCardCount());

  Serial.println("Estado de relés:");
  for (int i = 0; i < relayManager.getNumRelays(); i++) {
    Serial.print("  Relé ");
    Serial.print(i + 1);
    Serial.print(": ");
    Serial.print(relayManager.getRelayState(i) ? "ON" : "OFF");
    if (relayManager.getRelayState(i)) {
      unsigned long uptime = relayManager.getRelayUptime(i);
      Serial.print(" (Tiempo: ");
      Serial.print(uptime / 1000);
      Serial.print("s)");
    }
    Serial.println();
  }

  Serial.print("Google Sheets: ");
  Serial.println(sheetsManager.isConnected() ? "Conectado" : "Desconectado");

  Serial.println("===========================\n");
}

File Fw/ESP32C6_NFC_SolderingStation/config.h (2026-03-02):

#ifndef CONFIG_H
#define CONFIG_H

// ============================================
// Configuración de Hardware - ESP32-C6
// ============================================

// Pines para PN532 (I2C)
//#define PN532_SDA     6   // GPIO 6 - I2C Data
//#define PN532_SCL     7   // GPIO 7 - I2C Clock

// Pines para Relés (múltiples cautines soportados)
#define MAX_RELAYS    3   // Número máximo de relés

// Pines para Feedback
#define LED_GREEN     11  // GPIO 11 - LED Verde (éxito)

// ============================================
// Configuración de WiFi
// ============================================
#define WIFI_AP_NAME   "CatWAN_Relay"
#define WIFI_AP_PASS   "admin123"

// ============================================
// Configuración de NFC
// ============================================
#define NFC_SCAN_INTERVAL   500   // ms entre escaneos
#define NFC_DEBOUNCE_TIME   2000  // ms para evitar lectura repetida

// ================== ESTACIONES ==================
#define NUM_STATIONS 3

struct StationConfig {
    const char* stationId;
    int relayPin;
};

static StationConfig stations[NUM_STATIONS] = {
    { "ESTACION1", 8 },
    { "ESTACION2", 10 },
    { "ESTACION3", 1 }
};


// ============================================
// Configuración de Google Sheets / n8n
// ============================================
// Opción 1: Google Apps Script Web App
#define USE_GOOGLE_APPS_SCRIPT  false
#define GOOGLE_SCRIPT_URL       ""  // URL del Web App (configurar)

// Opción 2: n8n
#define USE_N8N                  true
#define N8N_WEBHOOK_URL          ""  // URL del webhook n8n (configurar)
#define N8N_TIME_WEBHOOK_URL     ""  // URL del webhook para hora (configurar)

// ============================================
// Configuración de Seguridad
// ============================================
#define MAX_USAGE_TIME      14400000  // 4 horas en ms (timeout seguridad)
#define MAX_FAILED_ATTEMPTS 5        // Intentos fallidos antes de bloquear

// ============================================
// Configuración de Almacenamiento
// ============================================
#define USE_SPIFFS            true   // Usar SPIFFS para tarjetas
#define USE_REMOTE_VALIDATION false   // Validar desde Google Sheets
#define MAX_AUTHORIZED_CARDS  20      // Máximo de tarjetas autorizadas (reducido para ahorrar memoria)
#define CARD_UID_LENGTH       8       // Longitud UID MIFARE S50

// ============================================
// Optimización de Memoria
// ============================================
#define DEBUG_SERIAL          true    // Activar/desactivar mensajes Serial
#define JSON_BUFFER_SIZE      256     // Tamaño del buffer JSON (reducido de 512)

// ============================================
// Configuración Serial
// ============================================
#define SERIAL_BAUD           115200
#define SERIAL_TIMEOUT        1000

#define DEVICE_ID "ESTACION_SOLDADURA_1"


// ============================================
// Comandos Serial
// ============================================
#define CMD_ADD_CARD      "ADD_CARD"
#define CMD_REMOVE_CARD   "REMOVE_CARD"
#define CMD_LIST_CARDS    "LIST_CARDS"
#define CMD_ASSIGN_CARD   "ASSIGN_CARD"
#define CMD_LIST_ASSIGN   "LIST_ASSIGN"
#define CMD_TEST_RELAY    "TEST_RELAY"
#define CMD_STATUS        "STATUS"
#define CMD_CLEAR_CARDS   "CLEAR_CARDS"
#define CMD_HELP          "HELP"
#define CMD_WIFI_RECONNECT "WIFI_RECONNECT"


#endif // CONFIG_H

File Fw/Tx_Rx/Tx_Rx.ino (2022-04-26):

#include <SPI.h>
#include <LoRa.h>
//#define LORA
#define SERIAL

String dato="";
int serialData[3];
bool flag_g=0;

int counter = 0;
bool stat0=1;
bool stat1=1;
bool stat2=1;

void interrupt(){
  flag_g=1;
  }

void transmit(){
    int bitOne = !digitalRead(0);
    int bitTwo = !digitalRead(1);
    int bitThree = !digitalRead(2);
    #ifdef LORA
    LoRa.beginPacket();
    LoRa.write(bitOne);
    LoRa.write(bitTwo);
    LoRa.write(bitThree);
    LoRa.endPacket();
    #endif
    Serial.println(String(bitOne)+String(bitTwo)+String(bitThree));
  }
  
void setup() {
  Serial.begin(115200);
  
  #ifdef SERIAL
  while(!Serial);
  #endif
  
  #ifdef LORA
  LoRa.setPins(SS, RFM_RST, RFM_DIO0);
  if (!LoRa.begin(915E6)) {
    Serial.println("Starting LoRa failed!");
    while (1);
  }
  #endif
  
  pinMode(0,INPUT); 
  pinMode(1,INPUT); 
  pinMode(2,INPUT); 
  pinMode(Relay_1,OUTPUT);
  pinMode(Relay_2,OUTPUT);
  pinMode(Relay_3,OUTPUT);
  pinMode(14,OUTPUT);

  attachInterrupt(0, interrupt, CHANGE);
  attachInterrupt(1,interrupt, CHANGE);
  attachInterrupt(2,interrupt, CHANGE);
  
  digitalWrite(14,LOW);
}

void loop() {
   if(flag_g){
    detachInterrupt(0);
    detachInterrupt(1);
    detachInterrupt(2);
    delay(20);
    transmit();
    attachInterrupt(0, interrupt, CHANGE);
    attachInterrupt(1,interrupt, CHANGE);
    attachInterrupt(2,interrupt, CHANGE);
    flag_g=0;
    } 

  #ifdef LORA
  int packetSize = LoRa.parsePacket();
  if (packetSize) {
    digitalWrite(14,HIGH);
    int dato[3];
    int i=0;
    if(LoRa.available()>4)return;
    while (LoRa.available()) {
      dato[i]=LoRa.read();
      Serial.println(dato[i]);
      i++;
    }
    digitalWrite(Relay_1,!dato[0]);
    digitalWrite(Relay_2,!dato[1]);
    digitalWrite(Relay_3,!dato[2]);
    digitalWrite(14,LOW);
  }
  #endif

  #ifdef SERIAL
  if(Serial.available()>0){
    int i=0;
    while(Serial.available()){
      serialData[i]=Serial.read()-48;
      i++;
    }    
    digitalWrite(Relay_1,serialData[0]);
    digitalWrite(Relay_2,serialData[1]);
    digitalWrite(Relay_3,serialData[2]);
    Serial.println("ok");
    }
  #endif 
 
}

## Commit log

2018-08-22 Add KiCAD project
    [CatWAN-Relay.kicad_pcb, CatWAN-Relay.sch, agroin-2018-07-31-18-16-12.sch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]
2018-12-19 Add schematic PDF
2019-05-22 Add possible pcb dimmensions
    [CatWAN-Relay.kicad_pcb]
2019-05-23 add measures
    [CatWAN-Relay.kicad_pcb]
2019-09-06 First route
    [CatWAN-Relay.kicad_pcb, CatWAN-Relay.sch]
2020-10-18 update labels and logos
    [CatWAN-Relay.kicad_pcb, CatWAN-Relay.sch]
2020-10-18 SWD SMD and fix labels
    [CatWAN-Relay.kicad_pcb]
2022-04-26 add serial control for relays
2022-04-26 update project to kicad6
2022-09-13 remove squematic oldversion
    [CatWAN-Relay.kicad_pcb]
2022-10-19 Update BOM
    [CatWAN-Relay.kicad_sch]
2024-10-26 feat: init CatWan relay 2
    [CatWAN-Relay.kicad_sch]
2024-11-05 fix: labels tx, rx and rx_leds
    [CatWAN-Relay.kicad_sch]
2024-11-05 feat(hw): USB C schematic changed & fusible added & references added
    [CatWAN-Relay.kicad_sch]
2024-11-06 feat: UPDATE BOM & diode changed
    [CatWAN-Relay.kicad_pcb, CatWAN-Relay.kicad_sch]
2024-11-06 fix: label RX led
    [CatWAN-Relay.kicad_sch]
2024-11-07 feat(hw): Footprint added
    [CatWAN-Relay.kicad_pcb, CatWAN-Relay.kicad_sch]
2024-11-07 feat(hw): Change optocoupler and D1-D4 mfr# and update footprints
    [CatWAN-Relay.kicad_pcb, CatWAN-Relay.kicad_sch]
2024-11-07 feat(hw): Update ESP32-C6 and RFM95 mfr.#
    [CatWAN-Relay.kicad_sch]
2024-11-07 feat: components placed
    [CatWAN-Relay.kicad_pcb]
2024-11-08 feat: Boot and Reset buttons footprint changed
    [CatWAN-Relay.kicad_pcb, CatWAN-Relay.kicad_sch]
2024-11-08 Feat: floorplan added
    [CatWAN-Relay.kicad_pcb, CatWAN-Relay.kicad_sch, RFM95W-915S2--3DModel-STEP-56544.STEP]
2024-12-19 feat: add zone with no fill
    [CatWAN-Relay.kicad_pcb]
2024-12-19 feat: change routes width
    [CatWAN-Relay.kicad_pcb]
2024-12-19 fix: move labels
    [CatWAN-Relay.kicad_pcb]
2024-12-26 feat(hw): add labels in PCB design
    [CatWAN-Relay.kicad_pcb]
2025-11-05 feat: assign card with relay
2026-01-23 files_modified, READEME, .ino, .h, .cpp files_added, .h, .cpp
    [CatWAN-Relay.kicad_pcb]
2026-01-30 feat: fix ESP32 NFC to Google, add get time
2026-02-05 feat: files_modified, _pro, _pcb & _sch
    [CatWAN-Relay.kicad_pcb, CatWAN-Relay.kicad_sch, CatWAN-Relay.sch]
2026-02-05 feat: fix pcb
    [CatWAN-Relay.kicad_pcb]
